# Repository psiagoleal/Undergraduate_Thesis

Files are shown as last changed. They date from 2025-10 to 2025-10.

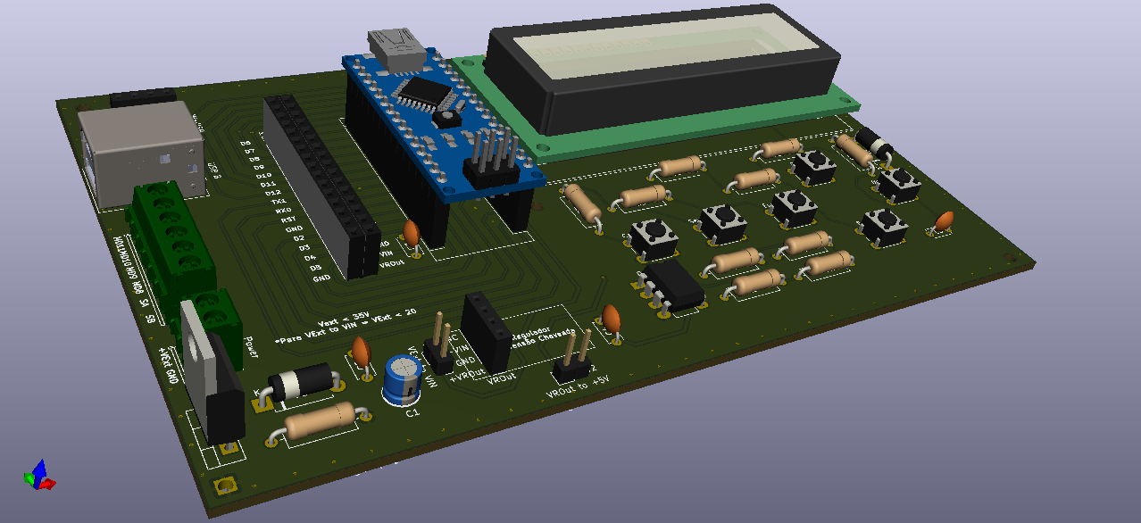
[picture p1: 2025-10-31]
hardware/TCC_diagonal.png

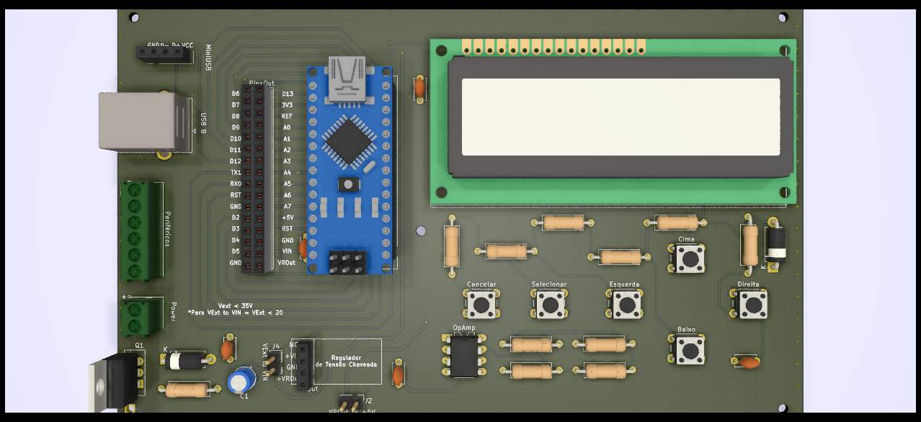
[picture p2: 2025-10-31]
hardware/TCC_top2.png

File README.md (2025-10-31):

# Automação de Interferômetro com Arduino (TCC)

Sistema de controle para um interferômetro de baixa coerência óptica (Michelson), desenvolvido em C++ para Arduino Nano e com hardware projetado em KiCAD. O sistema controla o movimento (passos) do espelho móvel com precisão, armazena posições na EEPROM e oferece interface por LCD/I2C ou via terminal serial.

Resumo do trabalho:
"DESENVOLVIMENTO DE UM SISTEMA DE CONTROLE DO INTERFERÔMETRO DE BAIXA COERÊNCIA PARA ESTUDOS DE ÍNDICE DE REFRAÇÃO EM MATERIAIS

Trabalho de Conclusão de Curso, apresentado à UEMS. Desenvolveu-se um sistema baseado em Arduino Nano para substituir o controle existente de um interferômetro de Michelson de baixa coerência (luz branca), utilizado para estudos de refração em materiais. O sistema controla o deslocamento do espelho móvel com precisão e permite configuração de parâmetros, armazenamento de posições e futura expansão com sensores/atuadores adicionais."

## Estrutura do repositório

- Hardware (KiCAD):
  - hardware/TCC.kicad_pcb, hardware/TCC.sch e arquivos auxiliares
  - hardware/Gerber/ (produção)
- Firmware (Arduino):
  - TCC8.0/src/main3.cpp — ponto de entrada do firmware
  - TCC8.0/lib — bibliotecas locais (LCD I2C, Soft I2C, Stepper, Interface, Config, etc.)
    - Interface gráfica no LCD: [`UserInterface::mainScreen`](TCC8.0/lib/Interface/Interface.cpp), telas como [`UserInterface::Screen30`](TCC8.0/lib/Interface/Interface.cpp), [`UserInterface::Screen40`](TCC8.0/lib/Interface/Interface.cpp), [`UserInterface::Screen50`](TCC8.0/lib/Interface/Interface.cpp), [`UserInterface::Screen510`](TCC8.0/lib/Interface/Interface.cpp)
    - Interface serial (modo terminal): [`InterfaceSerial::mainScreen`](TCC8.0/lib/InterfaceSerial/InterfaceSerial.cpp), telas 50x/51x/52x
    - Lógica de controle e variáveis globais: [`Data`](TCC8.0/lib/Config/Config.h) e seus getters/setters (ex.: [`Data::getScreenNumber`](TCC8.0/lib/Config/Config.cpp))
    - Driver de motor de passo: [`mStepper`](TCC8.0/lib/mStepper/mStepper.cpp)
    - Leitura de botões/sensores analógicos: [`Analog`](TCC8.0/lib/analogPins/analogPins.cpp), incluindo homing: [`Analog::trailSetup`](TCC8.0/lib/analogPins/analogPins.cpp)
    - Armazenamento em EEPROM (posições): exemplos em [`Select::BttnS312`](TCC8.0/lib/CommandsBttnS/CommandsBttnS.cpp)
- Aplicativos auxiliares de serial:
  - SerialComApp/ (exemplos C++ para comunicação via porta serial)
- Arquivos antigos e referências:
  - legacy/, refs/

## Funcionalidades principais

- Controle de motor de passo 4 fios, com passos por volta configurados (padrão: 64)
- Interface de usuário por LCD (I2C) com menu:
  - Zero Relativo (10x)
  - Ajuste Fino (30x)
  - Ajuste Grosso (40x)
  - Posições Salvas (50x/51x/52x), incluindo Zero Absoluto e posições 1–3
- Modo alternativo por terminal serial (9600 bps), com telas equivalentes (50x–52x)
- Persistência de posições em EEPROM (Zero Abs e posições 1–3)
- Rotina de homing pela leitura analógica (A1) para encontrar início de trilha: [`Analog::trailSetup`](TCC8.0/lib/analogPins/analogPins.cpp)

## Como compilar e gravar

1. Requisitos
   - Arduino Nano (ATmega328P)
   - IDE Arduino (1.8.x ou superior) ou Arduino CLI/PlatformIO
   - Baud rate: 9600 bps (Serial)

2. Passos
   - Abra a pasta TCC8.0 como projeto (o arquivo principal é [TCC8.0/src/main3.cpp](TCC8.0/src/main3.cpp), que define `setup()` e `loop()`).
   - Se usar IDE Arduino, coloque a pasta TCC8.0 como sketch. As bibliotecas usadas estão vendorizadas em TCC8.0/lib (LiquidCrystal_I2C, SoftI2C, etc.).
   - Selecione a placa “Arduino Nano” e a porta correta (ex.: COMx no Windows ou /dev/ttyACMx no Linux).
   - Compile e faça o upload.

Observações:
- A interface (LCD vs. terminal) é selecionada em tempo de execução a partir de [`Data::getSerialCom`](TCC8.0/lib/Config/Config.cpp), configurada em [`setup`](TCC8.0/src/main3.cpp) via `sc.SerialComSetup()` e constantes `SerialComNo`/`SerialComYes`.

## Uso

- Inicialização:
  - O firmware executa o homing com [`Analog::trailSetup`](TCC8.0/lib/analogPins/analogPins.cpp) para levar o espelho à referência da trilha.
  - Em seguida, abre a tela inicial via [`UserInterface::mainScreen`](TCC8.0/lib/Interface/Interface.cpp) ou [`InterfaceSerial::mainScreen`](TCC8.0/lib/InterfaceSerial/InterfaceSerial.cpp), conforme o modo.

- Controles (botões):
  - Códigos definidos em [TCC8.0/src/main3.cpp](TCC8.0/src/main3.cpp): RIGHT=0, UP=1, DOWN=2, LEFT=3, SELECT=4, CANCEL=5.
  - A navegação de telas é baseada em `ScreenNumber` (veja [`Data::getScreenNumber`](TCC8.0/lib/Config/Config.cpp)) e as telas `ScreenXX()` em Interface/InterfaceSerial.

- Salvamento/recuperação de posições:
  - Zero Absoluto é exibido em [`UserInterface::Screen510`](TCC8.0/lib/Interface/Interface.cpp) e equivalentes na interface serial.
  - Posições 1–3 têm telas de visualização e comandos de salvamento, com escrita na EEPROM (ex.: [`Select::BttnS312`](TCC8.0/lib/CommandsBttnS/CommandsBttnS.cpp)).

## Hardware

- Projeto da controladora e integrações no diretório [hardware/](hardware/)
  - Arquivos do KiCAD: TCC.sch, TCC.kicad_pcb, fabricáveis em [hardware/Gerber/](hardware/Gerber/)
- LCD I2C (PCF8574) com biblioteca local [`LiquidCrystal_I2C`](TCC8.0/lib/LiquidCrystal_I2C/LiquidCrystal_I2C.h) e suporte a Soft I2C

## Desenvolvimento

- Organização do código:
  - Lógica/estado: [`Data`](TCC8.0/lib/Config/Config.h, TCC8.0/lib/Config/Config.cpp)
  - UI LCD: [`UserInterface`](TCC8.0/lib/Interface/Interface.h, TCC8.0/lib/Interface/Interface.cpp)
  - UI Serial: [`InterfaceSerial`](TCC8.0/lib/InterfaceSerial/InterfaceSerial.h, TCC8.0/lib/InterfaceSerial/InterfaceSerial.cpp)
  - Controle motor: [`mStepper`](TCC8.0/lib/mStepper/mStepper.h, TCC8.0/lib/mStepper/mStepper.cpp)
  - Botões/sensores: [`Analog`](TCC8.0/lib/analogPins/analogPins.h, TCC8.0/lib/analogPins/analogPins.cpp)

- Parâmetros importantes:
  - Passos por volta: `stepsPerRevolution = 64` em [TCC8.0/lib/Variables/Variables.h](TCC8.0/lib/Variables/Variables.h)
  - Velocidades ajustáveis nas telas de configuração (20x), exibidas por [`UserInterface::Screen210`](TCC8.0/lib/Interface/Interface.cpp) e [`InterfaceSerial::Screen211`](TCC8.0/lib/InterfaceSerial/InterfaceSerial.cpp)
  - Salvamento de posições na EEPROM com endereços calculados em [TCC8.0/lib/Variables/Variables.h](TCC8.0/lib/Variables/Variables.h)

## SerialComApp

Exemplos C++ para comunicação serial com o Arduino estão em [SerialComApp/](SerialComApp/). Úteis para testes de leitura/escrita em Linux/Windows.

## 📄 Licença

MIT

## Contato

Projeto de TCC (Engenharia Física) — automação de interferômetro com Arduino. Para dúvidas técnicas, consulte os arquivos-fonte referenciados acima.

Link para monografia: https://drive.google.com/file/d/1YRrOQsxsX27IK1LEwe4l2IJH7da19-2-/view?usp=drive_link

---
## Apoie

**Feito com ❤️ por Iago Leal** | [☕ Apoie o criador]

Se este projeto ajudou você, considere apoiar:

- Buy Me a Coffee: https://buymeacoffee.com/psiagoleal

<a href="https://buymeacoffee.com/psiagoleal" target="_blank" rel="noopener">
  Buy Me A Coffee
</a>

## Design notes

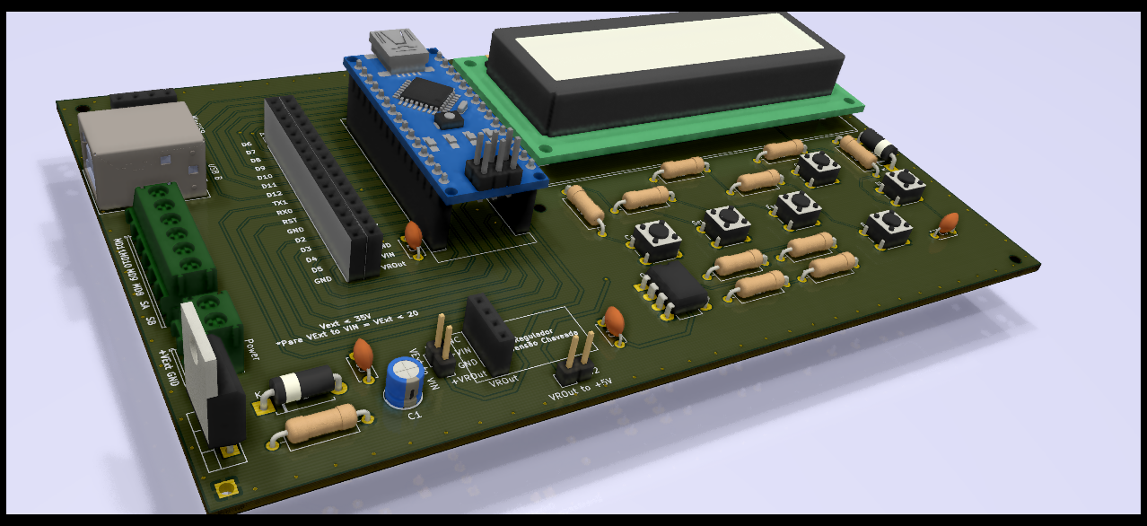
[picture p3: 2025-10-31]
hardware/TCC_diagonal2.png

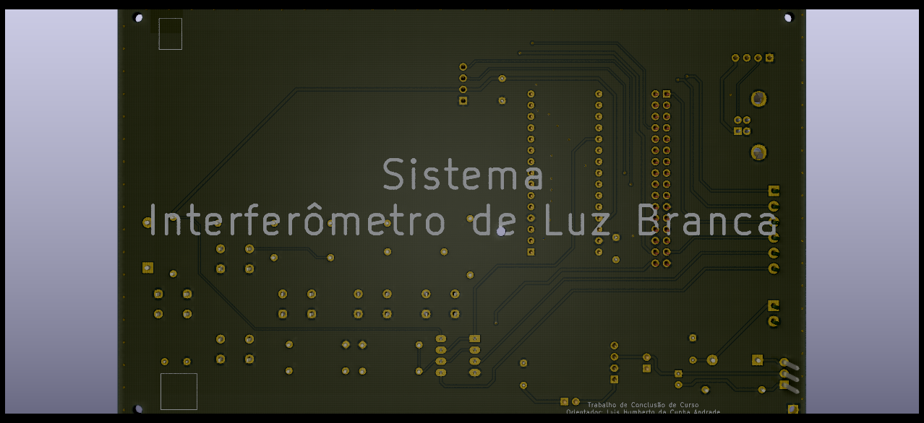
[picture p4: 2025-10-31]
hardware/TCC_bot2.png

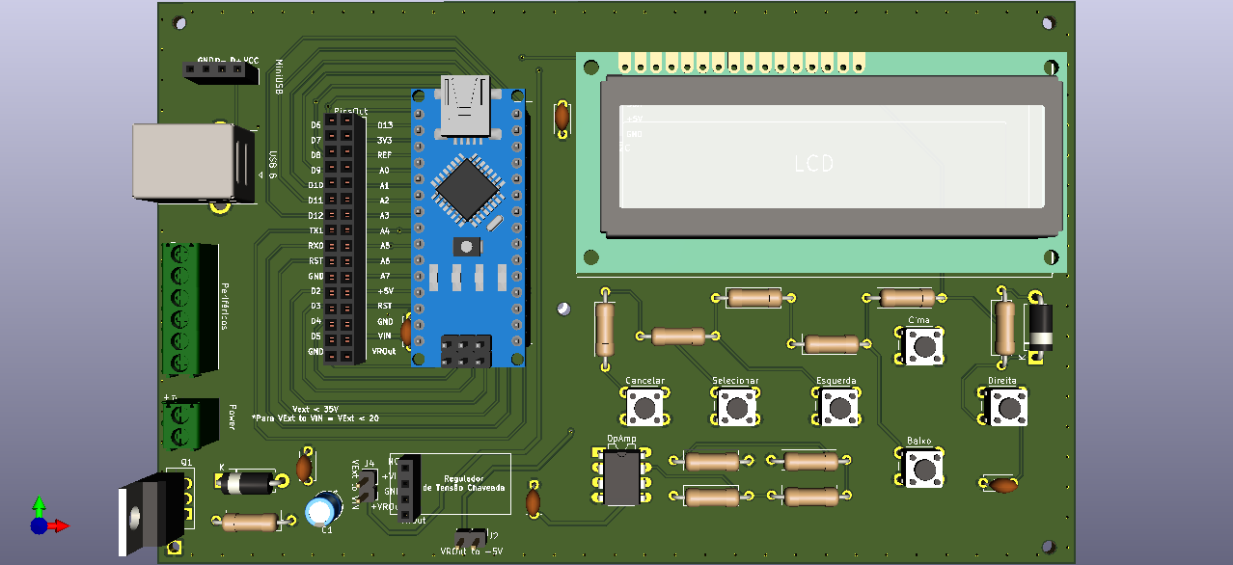
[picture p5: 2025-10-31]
hardware/TCC_top.png

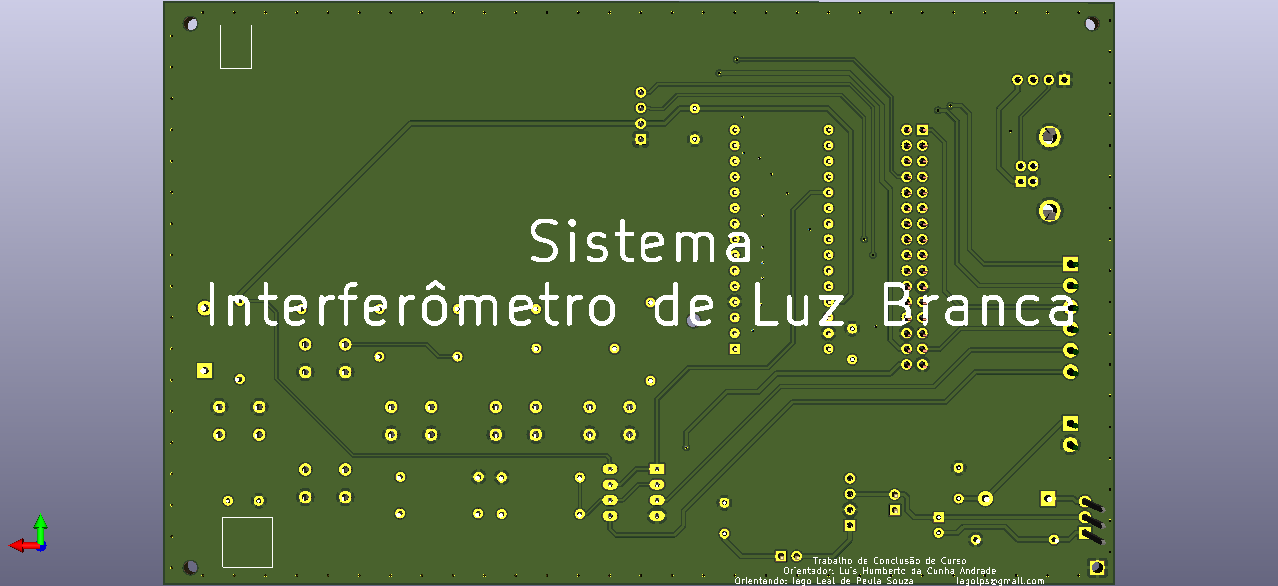
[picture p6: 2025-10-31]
hardware/TCC_bot.png

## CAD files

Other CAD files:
hardware/TCC.step
hardware/TCC2.step

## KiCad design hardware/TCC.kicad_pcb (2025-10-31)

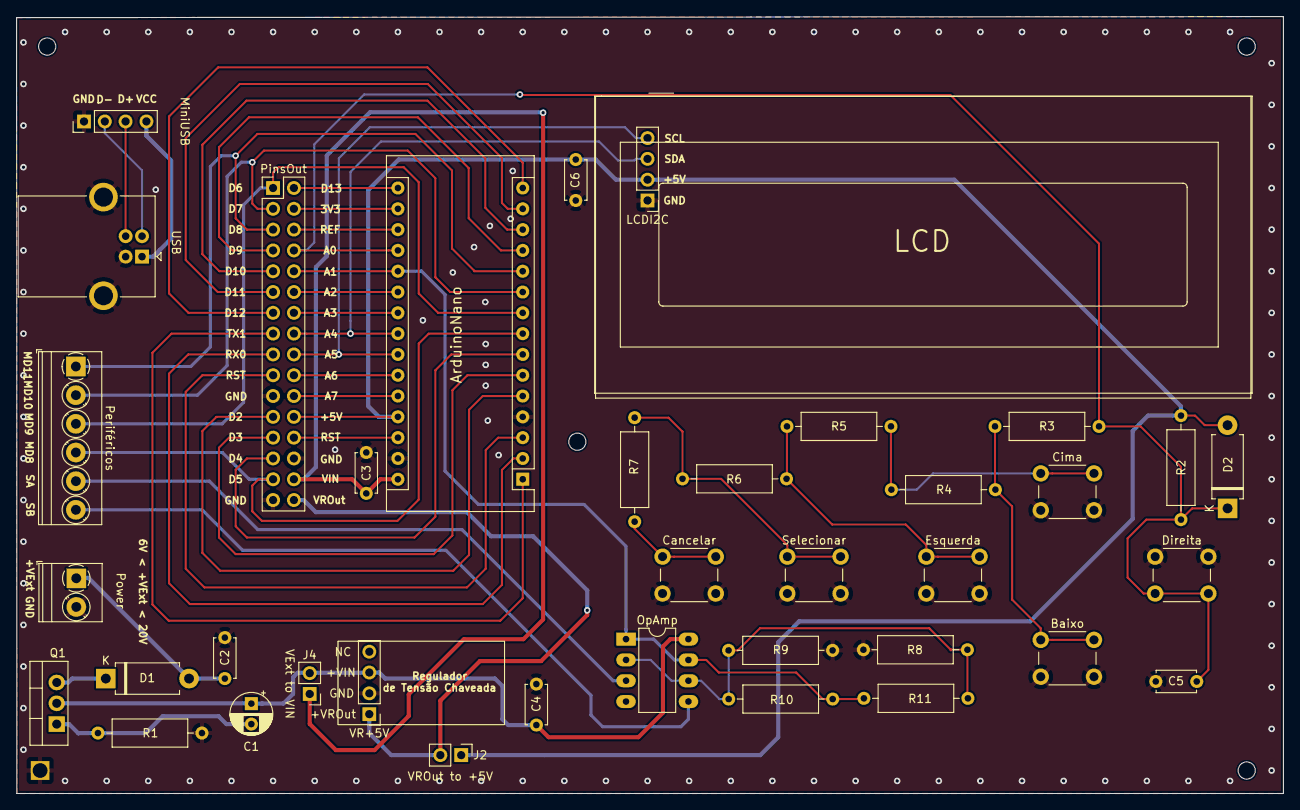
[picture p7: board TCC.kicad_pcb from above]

Board: 2 copper layers, 154.7 x 94.9 mm, 42 parts (0 on the bottom side), 45 nets.

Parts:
ArduinoNano: Arduino_Nano_v3.x; Arduino_Nano
Baixo: SW_Push; SW_PUSH_6mm_H4.3mm
C1: 100uF; CP_Radial_D5.0mm_P2.50mm
C2, C3, C4, C5, C6: 100pF; C_Disc_D4.7mm_W2.5mm_P5.00mm
Cancelar: SW_Push; SW_PUSH_6mm_H4.3mm
Cima: SW_Push; SW_PUSH_6mm_H4.3mm
D1: SB360; D_DO-15_P10.16mm_Horizontal
D2: SB140; D_DO-15_P10.16mm_Horizontal
Direita: SW_Push; SW_PUSH_6mm_H4.3mm
Esquerda: SW_Push; SW_PUSH_6mm_H4.3mm
J2, J4: 22-23-2021; PinHeader_1x02_P2.54mm_Vertical
LCDI2C: 0022232041; PinHeader_1x04_P2.54mm_Vertical
MiniUSB: 0022232041; PinHeader_1x04_P2.54mm_Vertical
OpAmp: LM358; DIP-8_W7.62mm_LongPads
Periféricos: Screw_Terminal_01x06; TerminalBlock_Phoenix_PT-1,5-6-3.5-H_1x06_P3.50mm_Horizontal
PinsOut: Female_Header_16x02_2.54; PinHeader_2x16_P2.54mm_Vertical
Power: Screw_Terminal_01x02; TerminalBlock_Phoenix_PT-1,5-2-3.5-H_1x02_P3.50mm_Horizontal
Q1: IRF9Z24; TO-220-3_Vertical
R1: 1M; R_Axial_DIN0309_L9.0mm_D3.2mm_P12.70mm_Horizontal
R2: 3k9; R_Axial_DIN0309_L9.0mm_D3.2mm_P12.70mm_Horizontal
R3, R4, R5, R6, R7: 220; R_Axial_DIN0309_L9.0mm_D3.2mm_P12.70mm_Horizontal
R8, R9, R10, R11: R; R_Axial_DIN0309_L9.0mm_D3.2mm_P12.70mm_Horizontal
REF1, REF2, REF3, REF4, REF5: MountingHole_2.1mm
Selecionar: SW_Push; SW_PUSH_6mm_H4.3mm
USB: USB_B; USB_B_OST_USB-B1HSxx_Horizontal
VR+5V: 0022232041; PinHeader_1x04_P2.54mm_Vertical

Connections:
1: ArduinoNano.1, PinsOut.8
2: ArduinoNano.2, PinsOut.9
3: ArduinoNano.3, PinsOut.10
5: ArduinoNano.5, PinsOut.12
6: ArduinoNano.6, PinsOut.13
7: ArduinoNano.7, PinsOut.14
8: ArduinoNano.8, Periféricos.4, PinsOut.15
9: ArduinoNano.9, Periféricos.3, PinsOut.1
10: ArduinoNano.10, Periféricos.2, PinsOut.2
11: ArduinoNano.11, Periféricos.1, PinsOut.3
12: ArduinoNano.12, PinsOut.4
13: ArduinoNano.13, PinsOut.5
14: ArduinoNano.14, PinsOut.6
15: ArduinoNano.15, PinsOut.7
16: ArduinoNano.16, PinsOut.17
17: ArduinoNano.17, PinsOut.18
18: ArduinoNano.18, PinsOut.19
19: ArduinoNano.19, C5.1, D2.1, Direita.2, PinsOut.20, R2.2, R3.2
20: ArduinoNano.20, OpAmp.1, OpAmp.7, PinsOut.21, R10.1, R11.1
21: ArduinoNano.21, PinsOut.22
22: ArduinoNano.22, PinsOut.23
23: ArduinoNano.23, LCDI2C.3, PinsOut.24
24: ArduinoNano.24, LCDI2C.4, PinsOut.25
25: ArduinoNano.25, PinsOut.26
26: ArduinoNano.26, PinsOut.27
28: ArduinoNano.28, PinsOut.29
29: ArduinoNano.4, ArduinoNano.29, Baixo.2, C2.2, C3.2, C4.2, C5.2, C6.1, Cancelar.2, Cima.2, Direita.1, Esquerda.2, LCDI2C.1, MiniUSB.1, PinsOut.11, PinsOut.16, PinsOut.30, Power.2, R1.2, R8.2, R9.2, REF4.1, Selecionar.2, USB.4, USB.5, VR+5V.2
30: ArduinoNano.30, C3.1, J4.1, PinsOut.31
+5V: ArduinoNano.27, C6.2, D2.2, J2.1, LCDI2C.2, PinsOut.28, R2.1
+VIN: C1.1, C4.1, J4.2, OpAmp.8, Q1.2, VR+5V.3
+VOUT: J2.2, PinsOut.32, VR+5V.1
unnamed: Baixo.1, R3.1, R4.1
unnamed: C1.2, Q1.1, R1.1
unnamed: Cancelar.1, R7.2
unnamed: Cima.1, R4.2, R5.1
unnamed: D1.1, Q1.3
unnamed: Esquerda.1, R5.2, R6.1
unnamed: MiniUSB.2, USB.2
unnamed: MiniUSB.3, USB.3
unnamed: MiniUSB.4, USB.1
unnamed: OpAmp.2, OpAmp.6, R8.1, R9.1, R10.2, R11.2
unnamed: R6.2, R7.1, Selecionar.1
SA: OpAmp.3, Periféricos.5
SB: OpAmp.5, Periféricos.6
VCC: C2.1, D1.2, Power.1

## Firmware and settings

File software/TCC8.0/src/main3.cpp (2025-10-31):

//BIBLIOTECAS
#include "Arduino.h"
#include "LiquidCrystal_I2C.h"
#include "mStepper.h"
#include "Config.h"
#include "Interface.h"
#include "InterfaceSerial.h"
#include "SoftwareCom.h"
#include "analogPins.h"
#include "CommandsBttnC.h"
#include "CommandsBttnD.h"
#include "CommandsBttnL.h"
#include "CommandsBttnR.h"
#include "CommandsBttnS.h"
#include "CommandsBttnU.h"

Data v;
UserInterface in;
InterfaceSerial ins;
Analog a;
Can c;
Down d;
Left l;
Right r;
Select s;
Up up;
SoftwareCom sc;

const int btnRIGHT = 0;
const int btnUP = 1;
const int btnDOWN = 2;
const int btnLEFT = 3;
const int btnSELECT = 4;
const int btnCANCEL = 5;
const int btnNONE = 6;

const int continueTrail = 0;
const int beginingTrail = 1;
const int endTrail = 2;
const int sensorNONE = 3;

const int SerialComNo = 0;
const int SerialComYes = 1;

//SETUP
void setup()
{
// INICIANDO PORTA SERIAL
    Serial.begin(9600);                 
    while (!Serial) {;}
    Serial.print("Iniciando Setup");
// FOR DEBUGGING
    //  for (unsigned int i = 0 ; i < EEPROM.length() ; i++)
    //  {
    //    EEPROM.write(i, 0);
    //  }
    sc.SerialComSetup();
    if(v.getSerialCom() == SerialComNo)
    {
    in.setup(); 
    a.trailSetup();
    delay(4000);
    in.mainScreen();
    }
    if(v.getSerialCom() == SerialComYes)
    {
    ins.setup();
    Serial.println(v.getScreenNumber()); 
    a.trailSetup();
    delay(4000);
    ins.mainScreen();
    }
    Serial.print(" >> ");
    Serial.println("Ok!");
//////////////////////////////////////////////////////
}

//LOOP
void loop()
{
  unsigned long currentMillis = millis();

  switch (v.getSerialCom())
  {
    case SerialComNo:
    {
    //LEITURA DOS SENSORES NA TRILHA-PARADA TOTAL CASO CHEGUE EM ALGUMA EXTREMIDADE
      Serial.print("Processos");
      Serial.print(" >> ");
      Serial.print(v.getScreenNumber());
      Serial.print(" >> ");
      Serial.print(a.Read_Sensors());
      Serial.print(" >> ");
      v.setBttnCode(a.Read_Buttons());
      Serial.println(v.getBttnCode());

      switch (a.Read_Sensors())
      {
        case continueTrail:{break;}

        case beginingTrail:{in.Screen_beginingTrail();break;}

        case endTrail: {in.Screen_endTrail();break;}
      }
    //////////////////////////////////////////////////////

    //LEITURA DOS BOTÕES  

      switch (v.getBttnCode())
      {
        case btnRIGHT:
        {
          v.setPreviousMillis(currentMillis);
          v.setIsBacklightOn(true);
          // lcd.backlight();
          switch (v.getScreenNumber())
          {
            //MainMenu()
            case 1:{r.BttnR1();break;}
            //
            //ZeroAbs
            case 10:{r.BttnR10();break;}
            case 100:{r.BttnR100();break;}
            case 101:{r.BttnR101();break;}
            case 110:{r.BttnR110();break;}
            case 111:{r.BttnR111();break;}
            //
            //Config
            case 20:{r.BttnR20();break;}
            case 200:{r.BttnR200();break;}
            case 201:{r.BttnR201();break;}
            case 202:{r.BttnR202();break;}
            case 210:{r.BttnR210();break;}
            case 211:{r.BttnR211();break;}
            case 212:{r.BttnR212();break;}
            //
            //AjstFino
            case 30:{r.BttnR30();break;}
            case 300:{r.BttnR300();break;}
            case 310:{r.BttnR310();break;}
            case 311:{r.BttnR311();break;}
            case 312:{r.BttnR312();break;}
            //
            //AjstGrosso
            case 40:{r.BttnR40();break;}
            case 400:{r.BttnR400();break;}
            //
            //PosiçõesSalvas
            case 50:{r.BttnR50();break;}
            case 500:{r.BttnR500();break;}
            case 501:{r.BttnR501();break;}
            case 502:{r.BttnR502();break;}
            case 503:{r.BttnR503();break;}
            case 510:{r.BttnR510();break;}
            case 511:{r.BttnR511();break;}
            case 512:{r.BttnR512();break;}
            case 513:{r.BttnR513();break;}
            case 520:{r.BttnR520();break;}
            case 521:{r.BttnR521();break;}
            case 522:{r.BttnR522();break;}
            case 523:{r.BttnR523();break;}
            //
            //Exit
            case 60:{r.BttnR60();break;}
            //
          }       
          delay(v.getBttnDelay());
          break;
        }

        case btnLEFT:
        {
          v.setPreviousMillis(currentMillis);
          v.setIsBacklightOn(true);
          // lcd.backlight();
          switch (v.getScreenNumber())
          {
                    //MainMenu()
            case 1:{l.BttnL1();break;}
            //
            //ZeroAbs
            case 10:{l.BttnL10();break;}
            case 100:{l.BttnL100();break;}
            case 101:{l.BttnL101();break;}
            case 110:{l.BttnL110();break;}
            case 111:{l.BttnL111();break;}
            //
            //Config
            case 20:{l.BttnL20();break;}
            case 200:{l.BttnL200();break;}
            case 201:{l.BttnL201();break;}
            case 202:{l.BttnL202();break;}
            case 210:{l.BttnL210();break;}
            case 211:{l.BttnL211();break;}
            case 212:{l.BttnL212();break;}
            //
            //AjstFino
            case 30:{l.BttnL30();break;}
            case 300:{l.BttnL300();break;}
            case 310:{l.BttnL310();break;}
            case 311:{l.BttnL311();break;}
            case 312:{l.BttnL312();break;}
            //
            //AjstGrosso
            case 40:{l.BttnL40();break;}
            case 400:{l.BttnL400();break;}
            //
            //PosiçõesSalvas
            case 50:{l.BttnL50();break;}
            case 500:{l.BttnL500();break;}
            case 501:{l.BttnL501();break;}
            case 502:{l.BttnL502();break;}
            case 503:{l.BttnL503();break;}
            case 510:{l.BttnL510();break;}
            case 511:{l.BttnL511();break;}
            case 512:{l.BttnL512();break;}
            case 513:{l.BttnL513();break;}
            case 520:{l.BttnL520();break;}
            case 521:{l.BttnL521();break;}
            case 522:{l.BttnL522();break;}
            case 523:{l.BttnL523();break;}
            //
            //Exit
            case 60:{l.BttnL60();break;}
            //
          }
          delay(v.getBttnDelay());        
          break;
        }

        case btnUP:
        {
          v.setPreviousMillis(currentMillis);
          v.setIsBacklightOn(true);
          // lcd.backlight();
          switch (v.getScreenNumber())
          {
                    //MainMenu()
            case 1:{up.BttnU1();break;}
            //
            //ZeroAbs
            case 10:{up.BttnU10();break;}
            case 100:{up.BttnU100();break;}
            case 101:{up.BttnU101();break;}
            case 110:{up.BttnU110();break;}
            case 111:{up.BttnU111();break;}
            //
            //Config
            case 20:{up.BttnU20();break;}
            case 200:{up.BttnU200();break;}
            case 201:{up.BttnU201();break;}
            case 202:{up.BttnU202();break;}
            case 210:{up.BttnU210();break;}
            case 211:{up.BttnU211();break;}
            case 212:{up.BttnU212();break;}
            //
            //AjstFino
            case 30:{up.BttnU30();break;}
            case 300:{up.BttnU300();break;}
            case 310:{up.BttnU310();break;}
            case 311:{up.BttnU311();break;}
            case 312:{up.BttnU312();break;}
            //
            //AjstGrosso
            case 40:{up.BttnU40();break;}
            case 400:{up.BttnU400();break;}
            //
            //PosiçõesSalvas
            case 50:{up.BttnU50();break;}
            case 500:{up.BttnU500();break;}
            case 501:{up.BttnU501();break;}
            case 502:{up.BttnU502();break;}
            case 503:{up.BttnU503();break;}
            case 510:{up.BttnU510();break;}
            case 511:{up.BttnU511();break;}
            case 512:{up.BttnU512();break;}
            case 513:{up.BttnU513();break;}
            case 520:{up.BttnU520();break;}
            case 521:{up.BttnU521();break;}
            case 522:{up.BttnU522();break;}
            case 523:{up.BttnU523();break;}
            //
            //Exit
            case 60:{up.BttnU60();}
            //
          }
          delay(v.getBttnDelay());
          break;
        }

        case btnDOWN:
        {
          v.setPreviousMillis(currentMillis);
          v.setIsBacklightOn(true);
          // lcd.backlight();
          switch (v.getScreenNumber())
          {
                    //MainMenu()
            case 1:{d.BttnD1();}
            //
            //ZeroAbs
            case 10:{d.BttnD10();break;}
            case 100:{d.BttnD100();break;}
            case 101:{d.BttnD101();break;}
            case 110:{d.BttnD110();break;}
            case 111:{d.BttnD111();break;}
            //
            //Config
            case 20:{d.BttnD20();break;}
            case 200:{d.BttnD200();break;}
            case 201:{d.BttnD201();break;}
            case 202:{d.BttnD202();break;}
            case 210:{d.BttnD210();break;}
            case 211:{d.BttnD211();break;}
            case 212:{d.BttnD212();break;}
            //
            //AjstFino
            case 30:{d.BttnD30();break;}
            case 300:{d.BttnD300();break;}
            case 310:{d.BttnD310();break;}
            case 311:{d.BttnD311();break;}
            case 312:{d.BttnD312();break;}
            //
            //AjstGrosso
            case 40:{d.BttnD40();break;}
            case 400:{d.BttnD400();break;}
            //
            //PosiçõesSalvas
            case 50:{d.BttnD50();break;}
            case 500:{d.BttnD500();break;}
            case 501:{d.BttnD501();break;}
            case 502:{d.BttnD502();break;}
            case 503:{d.BttnD503();break;}
            case 510:{d.BttnD510();break;}
            case 511:{d.BttnD511();break;}
            case 512:{d.BttnD512();break;}
            case 513:{d.BttnD513();break;}
            case 520:{d.BttnD520();break;}
            case 521:{d.BttnD521();break;}
            case 522:{d.BttnD522();break;}
            case 523:{d.BttnD523();break;}
            //
            //Exit
            case 60:{d.BttnD60();break;}
            //
          }        
          delay(v.getBttnDelay());
          break;
        }

        case btnSELECT:
        {
          v.setPreviousMillis(currentMillis);
          v.setIsBacklightOn(true);
          // lcd.backlight();
          switch (v.getScreenNumber())
          {
                    //MainMenu()
            case 1:{s.BttnS1();break;}
            //
            //ZeroAbs
            case 10:{s.BttnS10();break;}
            case 100:{s.BttnS100();break;}
            case 101:{s.BttnS101();break;}
            case 110:{s.BttnS110();break;}
            case 111:{s.BttnS111();break;}
            //
            //Config
            case 20:{s.BttnS20();break;}
            case 200:{s.BttnS200();break;}
            case 201:{s.BttnS201();break;}
            case 202:{s.BttnS202();break;}
            case 210:{s.BttnS210();break;}
            case 211:{s.BttnS211();break;}
            case 212:{s.BttnS212();break;}
            //
            //AjstFino
            case 30:{s.BttnS30();break;}
            case 300:{s.BttnS300();break;}
            case 310:{s.BttnS310();break;}
            case 311:{s.BttnS311();break;}
            case 312:{s.BttnS312();break;}
            //
            //AjstGrosso
            case 40:{s.BttnS40();break;}
            case 400:{s.BttnS400();break;}
            //
            //PosiçõesSalvas
            case 50:{s.BttnS50();break;}
            case 500:{s.BttnS500();break;}
            case 501:{s.BttnS501();break;}
            case 502:{s.BttnS502();break;}
            case 503:{s.BttnS503();break;}
            case 510:{s.BttnS510();break;}
            case 511:{s.BttnS511();break;}
            case 512:{s.BttnS512();break;}
            case 513:{s.BttnS513();break;}
            case 520:{s.BttnS520();break;}
            case 521:{s.BttnS521();break;}
            case 522:{s.BttnS522();break;}
            case 523:{s.BttnS523();break;}
            //
            //Exit
            case 60:{s.BttnS60();break;}
            //
          }
          delay(v.getBttnDelay());
          break;
        }
        case btnCANCEL:
        {
          v.setPreviousMillis(currentMillis);
          v.setIsBacklightOn(true);
          // lcd.backlight();
          switch (v.getScreenNumber())
          {
            //MainMenu()
            case 1:{c.BttnC1();break;}
            //
            //ZeroAbs
            case 10:{c.BttnC10();break;}
            case 100:{c.BttnC100();break;}
            case 101:{c.BttnC101();break;}
            case 110:{c.BttnC110();break;}
            case 111:{c.BttnC111();break;}
            //
            //Config
            case 20:{c.BttnC20();break;}
            case 200:{c.BttnC200();break;}
            case 201:{c.BttnC201();break;}
            case 202:{c.BttnC202();break;}
            case 210:{c.BttnC210();break;}
            case 211:{c.BttnC211();break;}
            case 212:{c.BttnC212();break;}
            //
            //AjstFino
            case 30:{c.BttnC30();break;}
            case 300:{c.BttnC300();break;}
            case 310:{c.BttnC310();break;}
            case 311:{c.BttnC311();break;}
            case 312:{c.BttnC312();break;}
            //
            //AjstGrosso
            case 40:{c.BttnC40();break;}
            case 400:{c.BttnC400();break;}
            //
            //PosiçõesSalvas
            case 50:{c.BttnC50();break;}
            case 500:{c.BttnC500();break;}
            case 501:{c.BttnC501();break;}
            case 502:{c.BttnC502();break;}
            case 503:{c.BttnC503();break;}
            case 510:{c.BttnC510();break;}
            case 511:{c.BttnC511();break;}
            case 512:{c.BttnC512();break;}
            case 513:{c.BttnC513();break;}
            case 520:{c.BttnC520();break;}
            case 521:{c.BttnC521();break;}
            case 522:{c.BttnC522();break;}
            case 523:{c.BttnC523();break;}
            //
            //Exit
            case 60:{c.BttnC60();break;}
            //
          }
          delay(v.getBttnDelay());
          break;
        }
      }
    }

    case SerialComYes:
    {
      //LEITURA DOS SENSORES NA TRILHA-PARADA TOTAL CASO CHEGUE EM ALGUMA EXTREMIDADE
      if(v.getDebug() == 1)
      {
        Serial.print("Processos");
        Serial.print(" >> ");
        Serial.print(v.getScreenNumber());
        Serial.print(" >> ");
        Serial.print(a.Read_Sensors());
        Serial.print(" >> ");
        v.setBttnCode(a.Read_Buttons());
        Serial.println(v.getBttnCode());
      }
      else{;}

      switch (a.Read_Sensors())
      {
        case continueTrail:{break;}

        case beginingTrail:{ins.Screen_beginingTrail();break;}

        case endTrail: {ins.Screen_endTrail();break;}
      }
    //////////////////////////////////////////////////////

    //LEITURA DOS BOTÕES  
      sc.ReadBttn();

      switch (v.getBttnCode())
      {
        case btnRIGHT:
        {
          v.setPreviousMillis(currentMillis);
          v.setIsBacklightOn(true);
          // lcd.backlight();
          switch (v.getScreenNumber())
          {
            //MainMenu()
            case 1:{r.BttnR1();break;}
            //
            //ZeroAbs
            case 10:{r.BttnR10();break;}
            case 100:{r.BttnR100();break;}
            case 101:{r.BttnR101();break;}
            case 110:{r.BttnR110();break;}
            case 111:{r.BttnR111();break;}
            //
            //Config
            case 20:{r.BttnR20();break;}
            case 200:{r.BttnR200();break;}
            case 201:{r.BttnR201();break;}
            case 202:{r.BttnR202();break;}
            case 210:{r.BttnR210();break;}
            case 211:{r.BttnR211();break;}
            case 212:{r.BttnR212();break;}
            //
            //AjstFino
            case 30:{r.BttnR30();break;}
            case 300:{r.BttnR300();break;}
            case 310:{r.BttnR310();break;}
            case 311:{r.BttnR311();break;}
            case 312:{r.BttnR312();break;}
            //
            //AjstGrosso
            case 40:{r.BttnR40();break;}
            case 400:{r.BttnR400();break;}
            //
            //PosiçõesSalvas
            case 50:{r.BttnR50();break;}
            case 500:{r.BttnR500();break;}
            case 501:{r.BttnR501();break;}
            case 502:{r.BttnR502();break;}
            case 503:{r.BttnR503();break;}
            case 510:{r.BttnR510();break;}
            case 511:{r.BttnR511();break;}
            case 512:{r.BttnR512();break;}
            case 513:{r.BttnR513();break;}
            case 520:{r.BttnR520();break;}
            case 521:{r.BttnR521();break;}
            case 522:{r.BttnR522();break;}
            case 523:{r.BttnR523();break;}
            //
            //Exit
            case 60:{r.BttnR60();break;}
            //
          }       
          delay(v.getBttnDelay());
          break;
        }

        case btnLEFT:
        {
          v.setPreviousMillis(currentMillis);
          v.setIsBacklightOn(true);
          // lcd.backlight();
          switch (v.getScreenNumber())
          {
                    //MainMenu()
            case 1:{l.BttnL1();break;}
            //
            //ZeroAbs
            case 10:{l.BttnL10();break;}
            case 100:{l.BttnL100();break;}
            case 101:{l.BttnL101();break;}
            case 110:{l.BttnL110();break;}
            case 111:{l.BttnL111();break;}
            //
            //Config
            case 20:{l.BttnL20();break;}
            case 200:{l.BttnL200();break;}
            case 201:{l.BttnL201();break;}
            case 202:{l.BttnL202();break;}
            case 210:{l.BttnL210();break;}
            case 211:{l.BttnL211();break;}
            case 212:{l.BttnL212();break;}
            //
            //AjstFino
            case 30:{l.BttnL30();break;}
            case 300:{l.BttnL300();break;}
            case 310:{l.BttnL310();break;}
            case 311:{l.BttnL311();break;}
            case 312:{l.BttnL312();break;}
            //
            //AjstGrosso
            case 40:{l.BttnL40();break;}
            case 400:{l.BttnL400();break;}
            //
            //PosiçõesSalvas
            case 50:{l.BttnL50();break;}
            case 500:{l.BttnL500();break;}
            case 501:{l.BttnL501();break;}
            case 502:{l.BttnL502();break;}
            case 503:{l.BttnL503();break;}
            case 510:{l.BttnL510();break;}
            case 511:{l.BttnL511();break;}
            case 512:{l.BttnL512();break;}
            case 513:{l.BttnL513();break;}
            case 520:{l.BttnL520();break;}
            case 521:{l.BttnL521();break;}
            case 522:{l.BttnL522();break;}
            case 523:{l.BttnL523();break;}
            //
            //Exit
            case 60:{l.BttnL60();break;}
            //
          }
          delay(v.getBttnDelay());        
          break;
        }

        case btnUP:
        {
          v.setPreviousMillis(currentMillis);
          v.setIsBacklightOn(true);
          // lcd.backlight();
          switch (v.getScreenNumber())
          {
                    //MainMenu()
            case 1:{up.BttnU1();break;}
            //
            //ZeroAbs
            case 10:{up.BttnU10();break;}
            case 100:{up.BttnU100();break;}
            case 101:{up.BttnU101();break;}
            case 110:{up.BttnU110();break;}
            case 111:{up.BttnU111();break;}
            //
            //Config
            case 20:{up.BttnU20();break;}
            case 200:{up.BttnU200();break;}
            case 201:{up.BttnU201();break;}
            case 202:{up.BttnU202();break;}
            case 210:{up.BttnU210();break;}
            case 211:{up.BttnU211();break;}
            case 212:{up.BttnU212();break;}
            //
            //AjstFino
            case 30:{up.BttnU30();break;}
            case 300:{up.BttnU300();break;}
            case 310:{up.BttnU310();break;}
            case 311:{up.BttnU311();break;}
            case 312:{up.BttnU312();break;}
            //
            //AjstGrosso
            case 40:{up.BttnU40();break;}
            case 400:{up.BttnU400();break;}
            //
            //PosiçõesSalvas
            case 50:{up.BttnU50();break;}
            case 500:{up.BttnU500();break;}
            case 501:{up.BttnU501();break;}
            case 502:{up.BttnU502();break;}
            case 503:{up.BttnU503();break;}
            case 510:{up.BttnU510();break;}
            case 511:{up.BttnU511();break;}
            case 512:{up.BttnU512();break;}
            case 513:{up.BttnU513();break;}
            case 520:{up.BttnU520();break;}
            case 521:{up.BttnU521();break;}
            case 522:{up.BttnU522();break;}
            case 523:{up.BttnU523();break;}
            //
            //Exit
            case 60:{up.BttnU60();}
            //
          }
          delay(v.getBttnDelay());
          break;
        }
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

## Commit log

2025-10-31 Track CAD/3D with Git LFS
    [TCC.step, TCC2.step]
2025-10-31 Atualizando com hardware e tentando organizar
    [TCC.dsn, TCC.kicad_pcb, TCC.sch]
